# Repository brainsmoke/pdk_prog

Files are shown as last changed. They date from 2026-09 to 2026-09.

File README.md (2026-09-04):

# Padauk programmer with USB-C connector

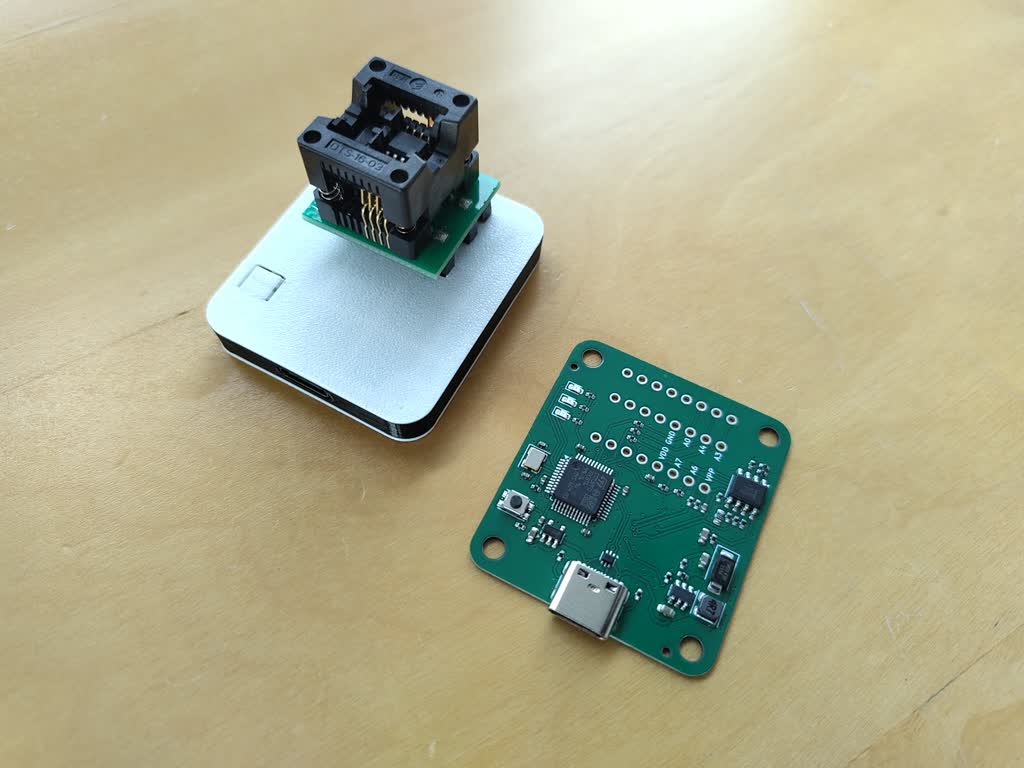
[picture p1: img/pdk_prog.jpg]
Image for the pcb, as well as one with a case and a soic8 zif socket on top


Production files (JLCPCB): [gerbers](build/pdk_prog/gerbers_jlc.zip) [BOM](build/pdk_prog/bomfile_jlc.csv) [POS](build/pdk_prog/posfile_jlc.csv)

Case: [case](build/pdk_prog/case.stl)

Circuit adapted from:

  https://github.com/free-pdk/easy-pdk-programmer-lite-hardware

Which in turn was adapted from:

  https://github.com/free-pdk/easy-pdk-programmer-hardware

Runs:

  https://github.com/free-pdk/easy-pdk-programmer-software

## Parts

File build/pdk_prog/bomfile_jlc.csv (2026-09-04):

Comment | Designator | Footprint | JLCPCB Part #
4.7uF | C1,C9,C12,C13 | Capacitor_SMD:C_0603_1608Metric | C19666
1uF | C2,C3,C4,C5,C6,C10,C11 | Capacitor_SMD:C_0402_1005Metric | C52923
10pF | C7,C8 | Capacitor_SMD:C_0402_1005Metric | C32949
SS14 | D4 | Diode_SMD:D_SMA | C2480
LED | D1,D2,D3 | LED_SMD:LED_0603_1608Metric | C2286
USB_C_Receptacle_USB2.0 | J1 | Library:USB_C_Receptacle_HRO_TYPE-C-31-M-12 | C165948
4.7uH | L1 | Inductor_SMD:L_Wuerth_MAPI-3015 | C7427089
22 | R13 | Resistor_SMD:R_0402_1005Metric | C25092
6k2 | R20 | Resistor_SMD:R_0603_1608Metric | C4260
3k9 | R26 | Resistor_SMD:R_0402_1005Metric | C51721
5k1 | R1,R2 | Resistor_SMD:R_0402_1005Metric | C25905
20k | R15,R17,R18,R19,R21 | Resistor_SMD:R_0402_1005Metric | C25765
220k | R22,R23,R24 | Resistor_SMD:R_0402_1005Metric | C25767
100k | R3,R8,R14,R16,R25 | Resistor_SMD:R_0402_1005Metric | C25741
330 | R4,R5,R6 | Resistor_SMD:R_0402_1005Metric | C25104
100 | R7,R9,R10,R11,R12 | Resistor_SMD:R_0402_1005Metric | C25076
SW_SPST | SW1 | Button_Switch_SMD:SW_Push_1P1T_NO_CK_KMR2 | C318893
STM32F072CBTx | U1 | Package_QFP:LQFP-48_7x7mm_P0.5mm | C81720
AP2112K-3.3 | U2 | Package_TO_SOT_SMD:SOT-23-5 | C51118
USBLC6-2P6 | U3 | Package_TO_SOT_SMD:SOT-666 | C15999
LM358 | U4 | Package_SO:SOIC-8_3.9x4.9mm_P1.27mm | C7950
MT3608 | U5 | Package_TO_SOT_SMD:SOT-23-6 | C84817
Crystal_GND24 | Y1 | Crystal:Crystal_SMD_3225-4Pin_3.2x2.5mm | C400090

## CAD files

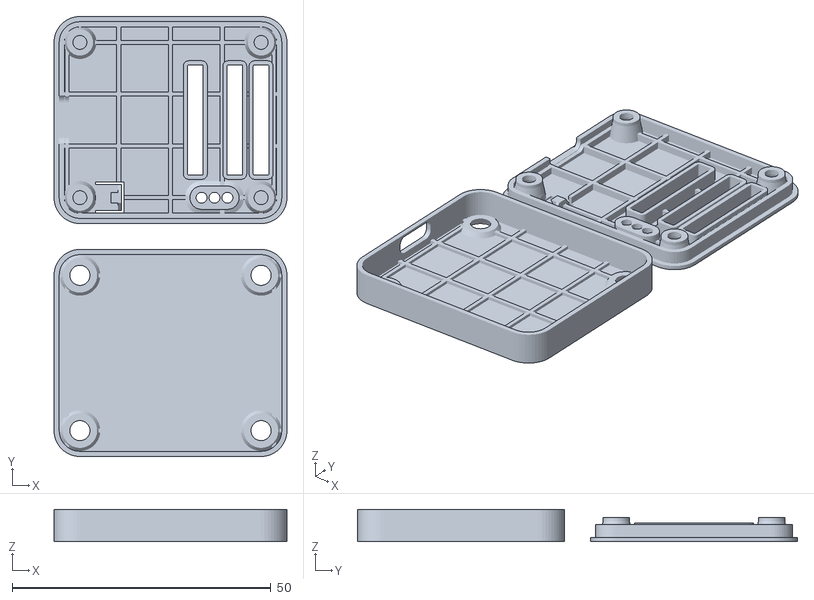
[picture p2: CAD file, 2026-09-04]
build/pdk_prog/case.stl
45.0 x 85.0 x 6.20

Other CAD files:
case/pdk_prog/case.scad
case/pdk_prog/case_pcb.scad
case/pdk_prog/pcb.scad
case/pdk_prog/gen/components.scad

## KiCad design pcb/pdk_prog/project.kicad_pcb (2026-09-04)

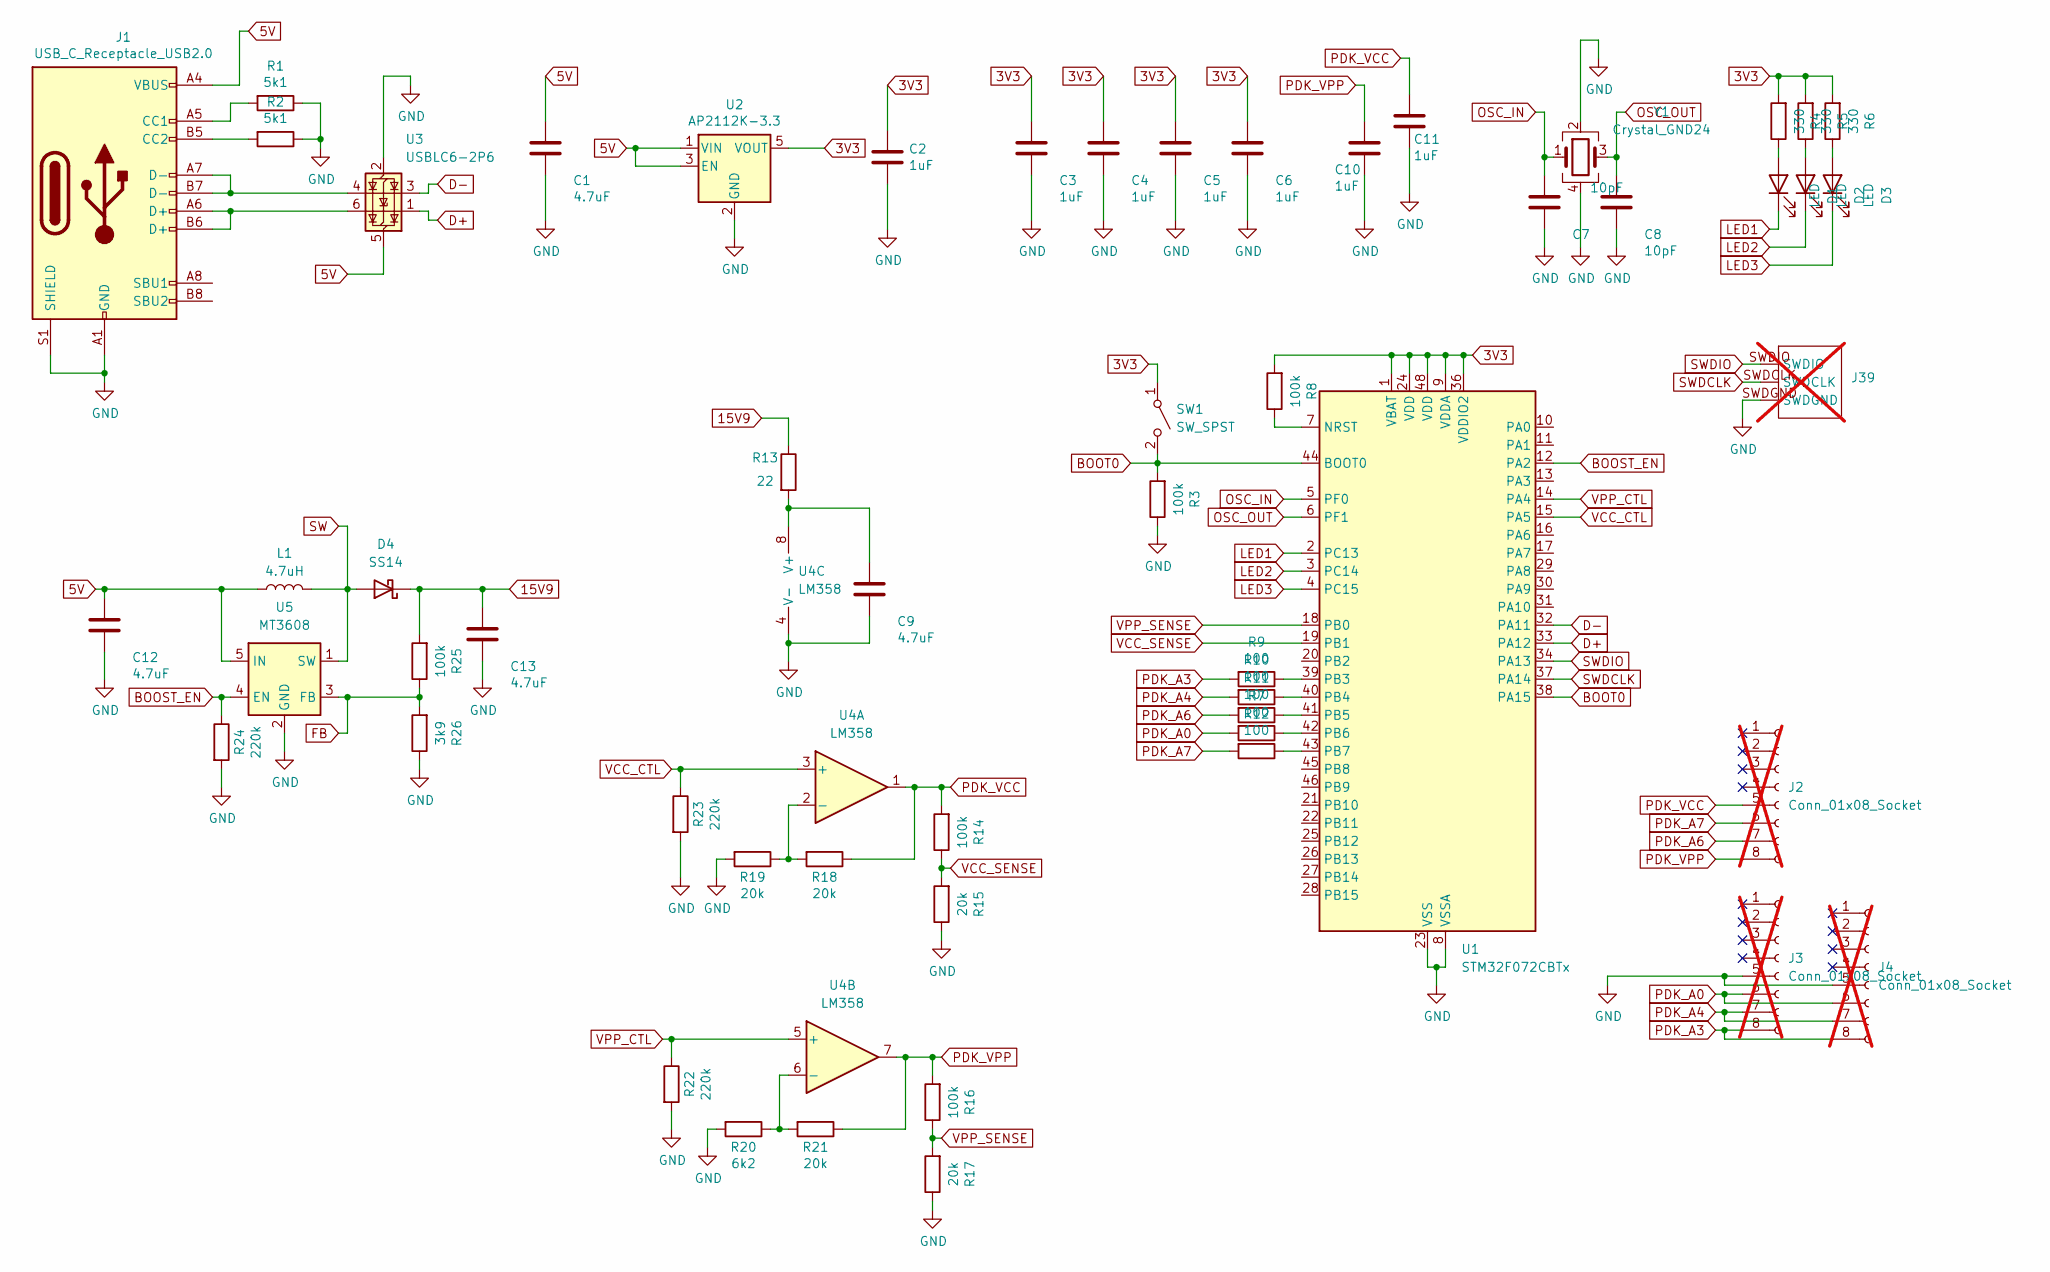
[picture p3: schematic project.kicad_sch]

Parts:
C1, C9, C12, C13: 4.7uF; C_0603_1608Metric; LCSC C19666
C2, C3, C4, C5, C6, C10, C11: 1uF; C_0402_1005Metric; LCSC C52923
C7, C8: 10pF; C_0402_1005Metric; LCSC C32949
D1, D2, D3: LED; LED_0603_1608Metric; LCSC C2286
D4: SS14; D_SMA; LCSC C2480
J1: USB_C_Receptacle_USB2.0; USB_C_Receptacle_HRO_TYPE-C-31-M-12; LCSC C165948
J2, J3, J4: Conn_01x08_Socket; PinSocket_1x08_P2.54mm_Vertical; not fitted
J39: SWDHeader_covered; not fitted
L1: 4.7uH; L_Wuerth_MAPI-3015; LCSC C7427089
R1, R2: 5k1; R_0402_1005Metric; LCSC C25905
R3, R8, R14, R16, R25: 100k; R_0402_1005Metric; LCSC C25741
R4, R5, R6: 330; R_0402_1005Metric; LCSC C25104
R7, R9, R10, R11, R12: 100; R_0402_1005Metric; LCSC C25076
R13: 22; R_0402_1005Metric; LCSC C25092
R15, R17, R18, R19, R21: 20k; R_0402_1005Metric; LCSC C25765
R20: 6k2; R_0603_1608Metric; LCSC C4260
R22, R23, R24: 220k; R_0402_1005Metric; LCSC C25767
R26: 3k9; R_0402_1005Metric; LCSC C51721
SW1: SW_SPST; SW_Push_1P1T_NO_CK_KMR2; LCSC C318893
U1: STM32F072CBTx; LQFP-48_7x7mm_P0.5mm; LCSC C81720
U2: AP2112K-3.3; SOT-23-5; LCSC C51118
U3: USBLC6-2P6; SOT-666; LCSC C15999
U4: LM358; SOIC-8_3.9x4.9mm_P1.27mm; LCSC C7950
U5: MT3608; SOT-23-6; LCSC C84817
Y1: Crystal_GND24; Crystal_SMD_3225-4Pin_3.2x2.5mm; LCSC C400090

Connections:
3V3: C2.1, C3.1, C4.1, C5.1, C6.1, R4.2, R5.2, R6.2, R8.2, SW1.1 (A), U1.1 (VBAT), U1.9 (VDDA), U1.24 (VDD), U1.36 (VDDIO2), U1.48 (VDD), U2.5 (VOUT)
5V: C1.1, C12.1, J1.A4 (VBUS), J1.A9 (VBUS), J1.B4 (VBUS), J1.B9 (VBUS), L1.1, U2.1 (VIN), U2.3 (EN), U3.5 (VBUS), U5.5 (IN)
15V9: C13.1, D4.1 (K), R13.1, R25.2
BOOST_EN: R24.1, U1.12 (PA2), U5.4 (EN)
BOOT0: R3.2, SW1.2 (B), U1.38 (PA15), U1.44 (BOOT0)
D+: U1.33 (PA12), U3.1 (I/O1)
D-: U1.32 (PA11), U3.3 (I/O2)
FB: R25.1, R26.2, U5.3 (FB)
GND: C1.2, C2.2, C3.2, C4.2, C5.2, C6.2, C7.2, C8.2, C9.2, C10.2, C11.2, C12.2, C13.2, J1.A1 (GND), J1.A12 (GND), J1.B1 (GND), J1.B12 (GND), J1.S1 (SHIELD), J3.5, J4.5, J39.SWDGND, R1.1, R2.1, R3.1, R15.1, R17.1, R19.2, R20.2, R22.2, R23.2, R24.2, R26.1, U1.8 (VSSA), U1.23 (VSS), U1.35 (VSS), U1.47 (VSS), U2.2 (GND), U3.2 (GND), U4.4 (V-), U5.2 (GND), Y1.2, Y1.4
LED1: D1.1 (K), U1.2 (PC13)
LED2: D2.1 (K), U1.3 (PC14)
LED3: D3.1 (K), U1.4 (PC15)
unnamed: D1.2 (A), R4.1
unnamed: D2.2 (A), R5.1
unnamed: D3.2 (A), R6.1
unnamed: J1.A5 (CC1), R1.2
unnamed: J1.B5 (CC2), R2.2
unnamed: J1.A6 (D+), J1.B6 (D+), U3.6 (I/O1)
unnamed: J1.A7 (D-), J1.B7 (D-), U3.4 (I/O2)
unnamed: R8.1, U1.7 (NRST)
unnamed: R9.1, U1.39 (PB3)
unnamed: R10.1, U1.40 (PB4)
unnamed: R11.1, U1.41 (PB5)
unnamed: R7.1, U1.42 (PB6)
unnamed: R12.1, U1.43 (PB7)
unnamed: R18.2, R19.1, U4.2 (-)
unnamed: R20.1, R21.2, U4.6 (-)
unnamed: C9.1, R13.2, U4.8 (V+)
OSC_IN: C7.1, U1.5 (PF0), Y1.1
OSC_OUT: C8.1, U1.6 (PF1), Y1.3
PDK_A0: J3.6, J4.6, R7.2
PDK_A3: J3.8, J4.8, R9.2
PDK_A4: J3.7, J4.7, R10.2
PDK_A6: J2.7, R11.2
PDK_A7: J2.6, R12.2
PDK_VCC: C11.1, J2.5, R14.2, R18.1, U4.1
PDK_VPP: C10.1, J2.8, R16.2, R21.1, U4.7
SW: D4.2 (A), L1.2, U5.1 (SW)
SWDCLK: J39.SWDCLK, U1.37 (PA14)
SWDIO: J39.SWDIO, U1.34 (PA13)
VCC_CTL: R23.1, U1.15 (PA5), U4.3 (+)
VCC_SENSE: R14.1, R15.2, U1.19 (PB1)
VPP_CTL: R22.1, U1.14 (PA4), U4.5 (+)
VPP_SENSE: R16.1, R17.2, U1.18 (PB0)

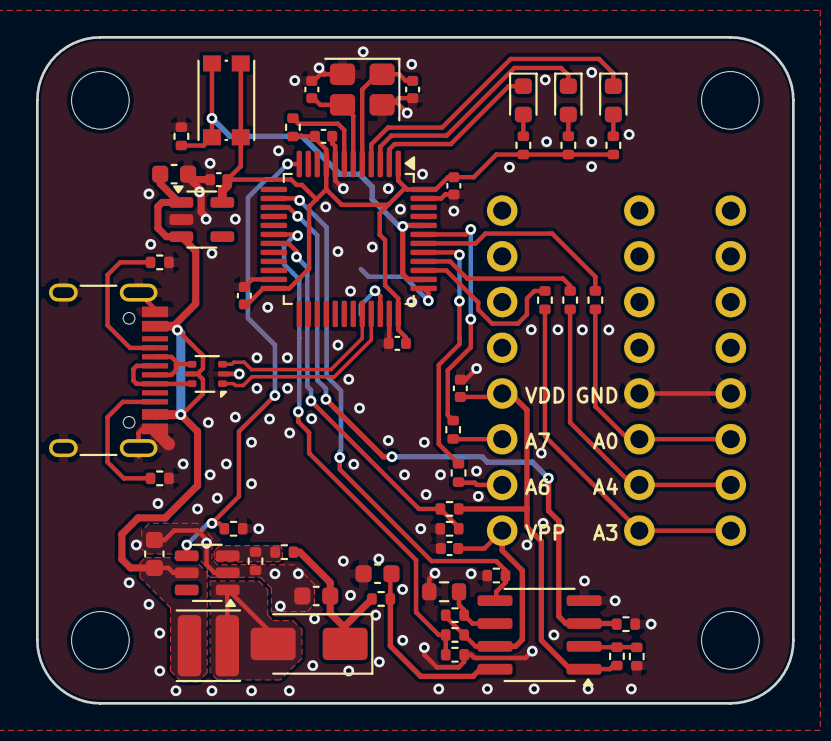
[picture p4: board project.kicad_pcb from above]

Board: 2 copper layers, 42.0 x 37.0 mm, 56 parts (1 on the bottom side), 44 nets.

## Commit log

2026-09-04 Padauk programmer with USB-C connector
    [bomfile_jlc.csv, case.scad, case.stl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]
2026-09-04 [case] fix margin around pinsocket
    [case.scad, case.stl]

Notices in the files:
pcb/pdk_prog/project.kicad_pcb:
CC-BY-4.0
